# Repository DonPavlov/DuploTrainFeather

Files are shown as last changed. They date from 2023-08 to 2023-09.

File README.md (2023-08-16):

# Duplo Train Controller with ESP32-S3 Feather

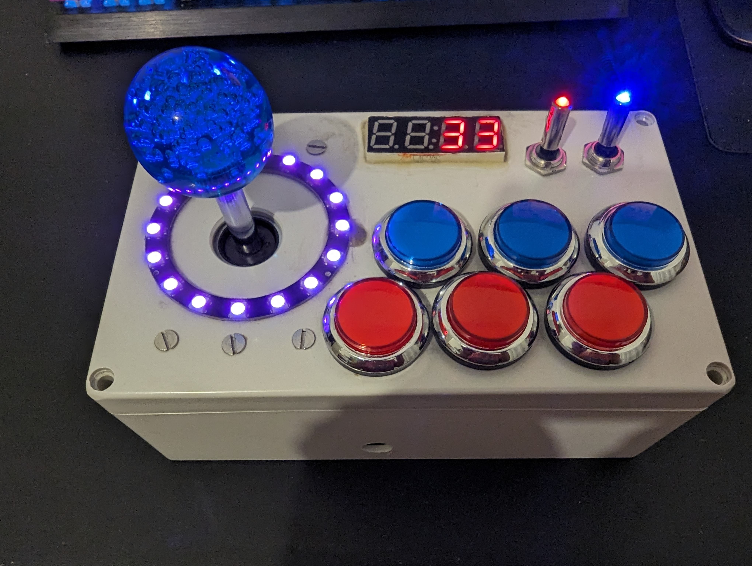
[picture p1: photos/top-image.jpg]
Project Image


This repository contains the code and resources for the 4th iteration of a Duplo train controller built using an ESP32-S3 Feather board. This iteration represents a culmination of learnings from previous iterations and offers enhanced features for controlling a Duplo train wirelessly via Bluetooth. The project features arcade buttons, a joystick, switches, LED indicators, an I2C 4-digit display, a Neopixel 16-pixel ring, and more, all integrated into a customized box.

## Features

- Control Duplo train speed with a joystick
- Trigger lights, sounds, and stop functionality with arcade buttons
- Display train speed on the I2C 4-digit display
- Create dynamic lighting effects using the Neopixel 16-pixel ring
- Use toggle switches for power control and additional functions
- Power everything via USB-C or the included LiPo battery for portability

## Iterations

### 1st Iteration

The first iteration of the project involved utilizing an Arduino Mega to trigger LEDs upon button presses. It served as the foundation for later iterations, focusing on the basic interaction with button inputs and LED outputs.

### 2nd Iteration

In the second iteration, an ESP32 was introduced along with a level shifter, enabling successful control of a Duplo train using button presses. This iteration addressed issues arising from previous AAA battery usage and shorting due to bent power pins.

### 3rd Iteration

The third iteration marked a significant advancement with a completely new PCB design powered by a LiFePO4 battery. However, issues arose concerning power consumption and the ESP32-S3's power requirements, posing challenges in achieving stable operation.

### 4th Iteration (Current)

The current 4th iteration builds upon lessons learned from previous versions. The project utilizes a single ESP32-S3 Feather board to control all functionalities, eliminating the Arduino Mega and AAA battery dependencies. This iteration aims to provide a refined and reliable Duplo train control experience. It is also using a MCP23017 GPIO Expander so only necessary GPIO is used on the Feather and no second microcontroller needs coordination.

## Setup

1. Get a Box to hold everything.
2. Get Arcade Buttons, leds, ESP32-S3 Feather board, MCP23017 Board, LiPo Battery, Neopixel Ring, Joystick, Toggle Switches and Copper-perfboard.
3. Follow the detailed wiring instructions and diagrams provided in the PCB Folder[](pcb/duplo-train-feather.png) 
4. Upload the provided code to your ESP32-S3 Feather board using the Arduino IDE or PlatformIO.

## Wiring Diagram

Please take a closer look inside the pcb folder. 
To open and edit install [Fritzing](https://fritzing.org/)

## Debugging of Feather Boards
Sometimes the ESP32-S3 Feather Board is not able to be flashed.
Follow these steps for a possible solution.
[Possible BugFix/Workaround](https://github.com/espressif/arduino-esp32/issues/8354#issuecomment-1669090415)

# Currently working solution
Upload via OTA, if that fails.
* Press Boot
* Press Reset
* Release Reset
* Release Boot
Flash again at correct COM4.

## License

This project is licensed under the [Unlicense](LICENSE).

---

Designed and developed by DonPavlov.

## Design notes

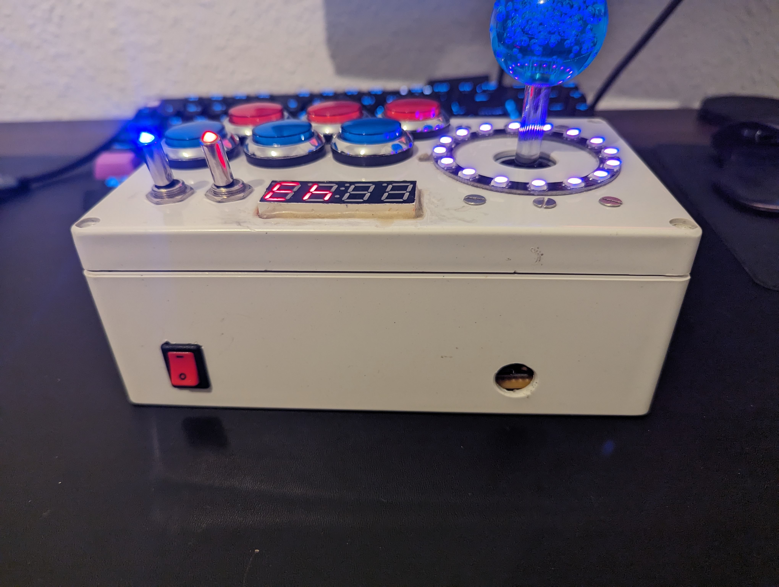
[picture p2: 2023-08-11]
photos/side-image.jpg

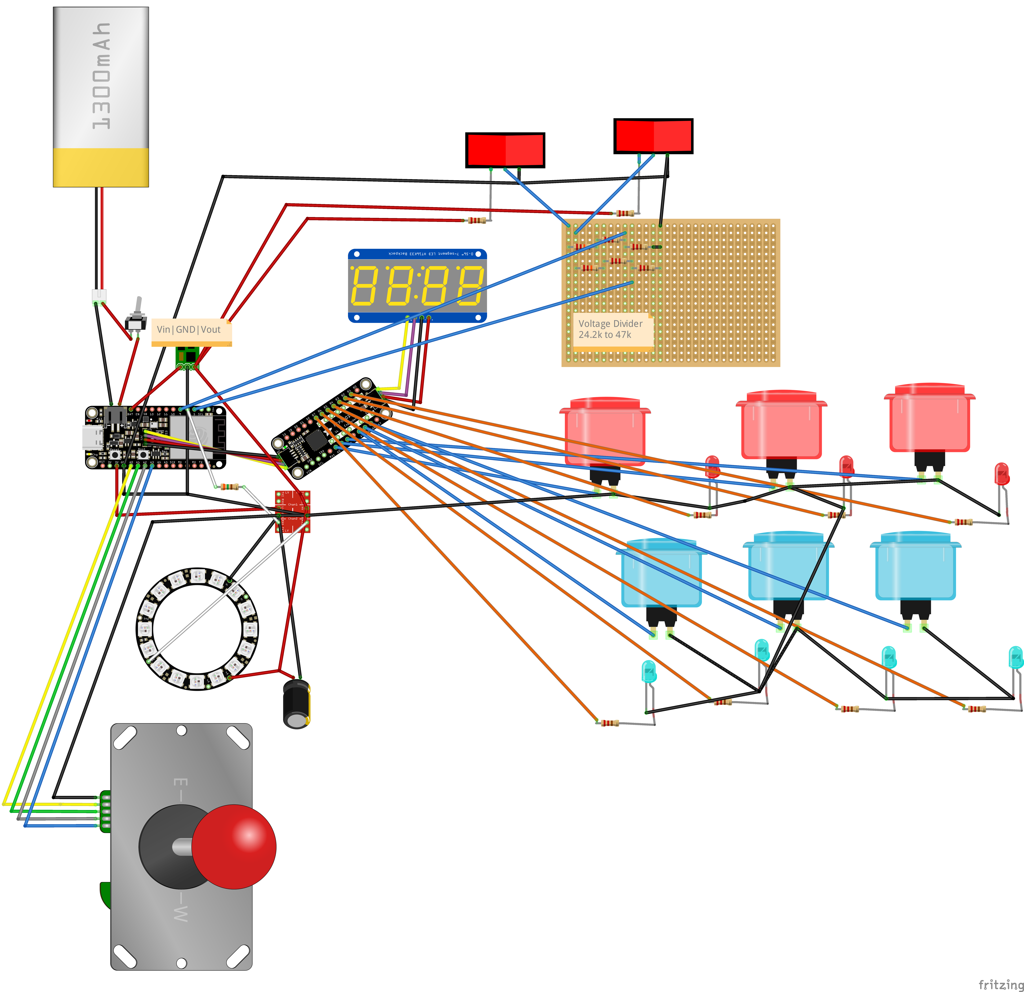
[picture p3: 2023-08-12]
pcb/duplo-train-feather.png

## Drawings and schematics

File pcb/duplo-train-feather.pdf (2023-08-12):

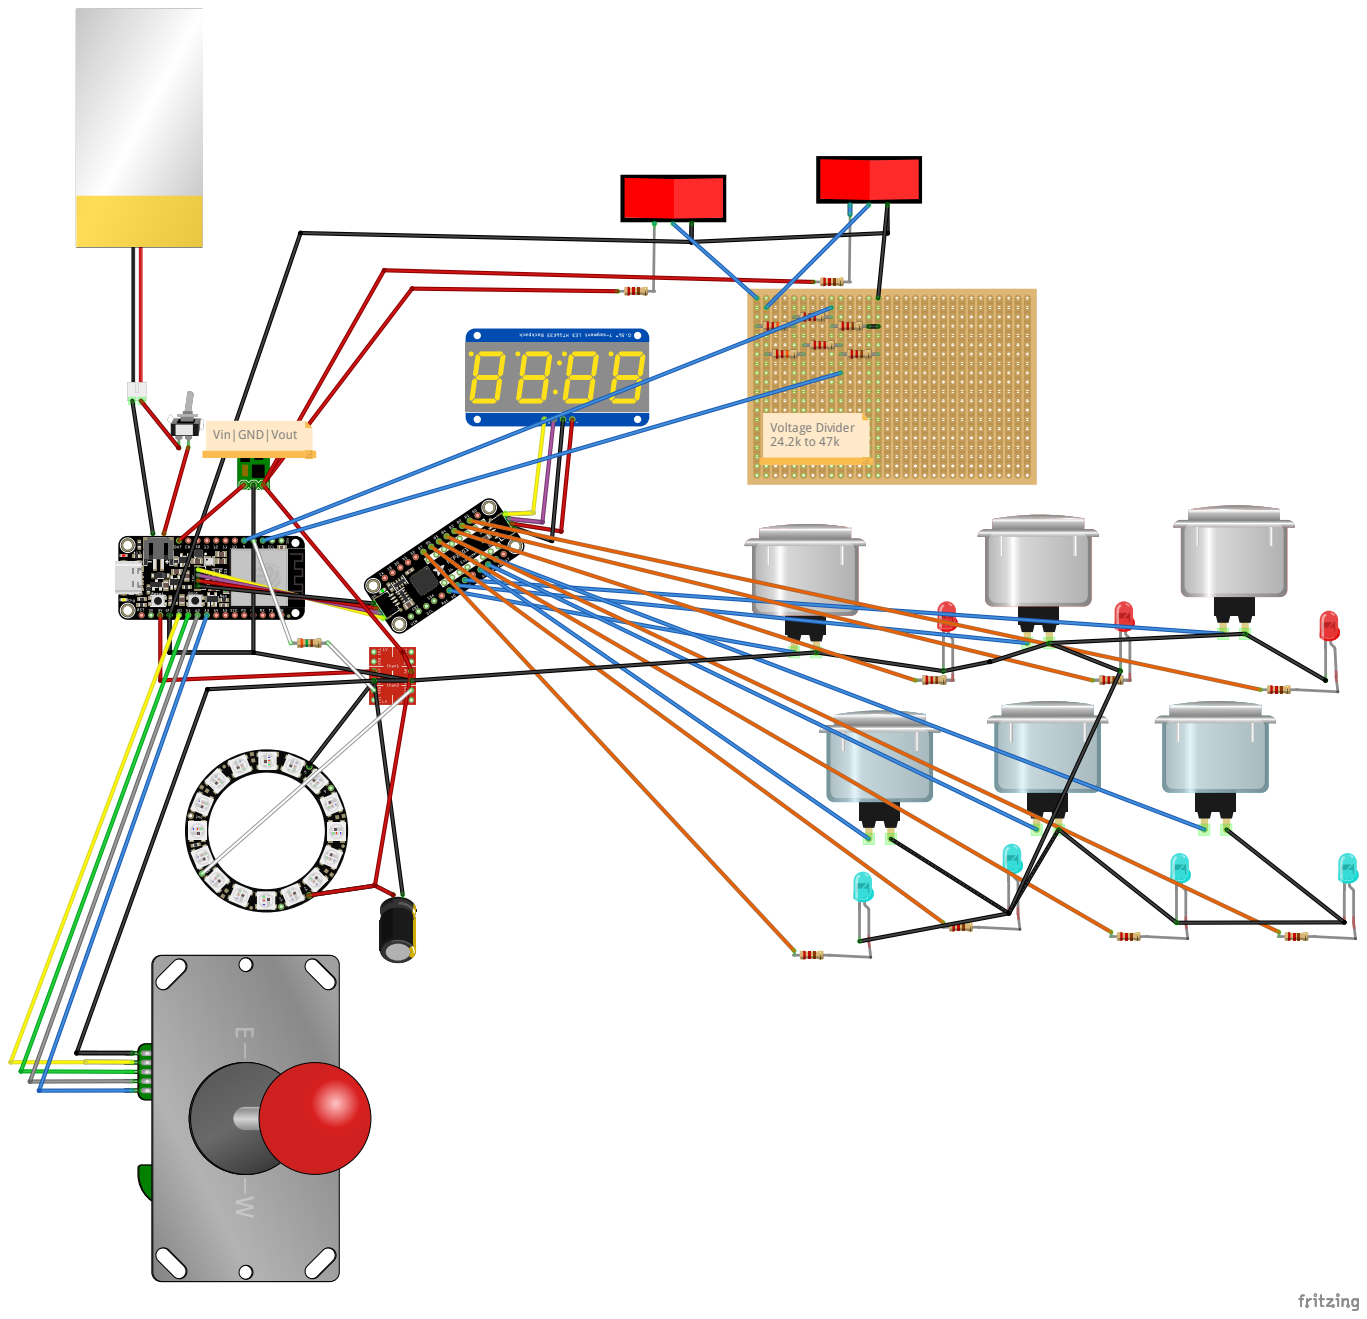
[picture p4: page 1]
Vin|G N; olt a; Divid e

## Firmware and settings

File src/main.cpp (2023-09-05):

#include "main.hpp"
#include <cstring>
#include <string>

#include "io.hpp"
#include "Lpf2Hub.h"
#include "Adafruit_LEDBackpack.h"
#include "Adafruit_NeoPixel.h"
#include <Adafruit_GFX.h>
#include "light_strip.hpp"

#include <Adafruit_MCP23X17.h>
#include "secrets.hpp"
#include <WiFi.h>
#include <ESPmDNS.h>
#include <WiFiUdp.h>
#include <ArduinoOTA.h>

// TODO include #include "Adafruit_MAX1704X.h" // for battery voltage monitoring


// UART1 GPIO 18 RX GPIO17 TX
#define RXD1 (18)
#define TXD1 (17)

Lpf2Hub m_Hub;
volatile int8_t g_speed { 0 };
volatile int8_t g_lastSpeed{ 0 };
bool m_connected{  false };
constexpr size_t buf_size { 32 };

#if (WIFI_MODE == 1)

// Set your Static IP address
IPAddress local_IP(192, 168, 178, 123);

// Set your Gateway IP address
IPAddress gateway(192, 168, 178, 1);

IPAddress subnet(255, 255, 255, 0);
IPAddress primaryDNS(8, 8, 8, 8);   // optional
IPAddress secondaryDNS(8, 8, 4, 4); // optional
#endif // if (WIFI_MODE == 1)
unsigned long startMillis;          // some global variables available anywhere in
                                    // the program
unsigned long currentMillis;
unsigned long wifiMillis;
unsigned long long_periodMillis;
const unsigned long period       { 25 }; // the value is a number of milliseconds
const unsigned long long_period  { 1000 };
const unsigned long wifi_timeout { 10000 };
bool wifiConSkipped              { false };
bool wifiSetupfinished           { false };

bool powerSaveMode { false };
const unsigned long powerSaveThreshold { 600000 }; // 1 minutes in milliseconds
unsigned long lastActivityTime         { 0 };
unsigned long executionTimeMillis { 0 };
unsigned long prevExecutionMillis { 0 };
unsigned long currentExecutionMillis { 0 };
constexpr unsigned long m_hub_delay { 20 };
constexpr unsigned long callback_execution_delay{ 50 };

LightStrip myStrip; // Create an instance of the LightStrip class

Adafruit_7segment matrix = Adafruit_7segment();
IO io_ctrl;

std::map<Commands::Commands, std::string> commandNames = {
  { Commands::Commands::Forward,
    "Forward" },
  { Commands::Commands::Backward,
    "Backward" },
  { Commands::Commands::Stop,
    "Stop" },
  { Commands::Commands::Light,
    "Light"   },
  { Commands::Commands::Refill,
    "Refill"    },
  { Commands::Commands::Horn,
    "Horn"  },
  { Commands::Commands::Steam,
    "Steam" },
  { Commands::Commands::Departure,
    "Departure" },
  { Commands::Commands::Faster,
    "Faster" },
  { Commands::Commands::Slower,
    "Slower" },
  { Commands::Commands::None,
    "None"  }
};

static void colorSensorCb(void      *hub,
                          byte       portNumber,
                          DeviceType deviceType,
                          uint8_t   *pData)
{
  Lpf2Hub *mHub = (Lpf2Hub *)hub;

  if (deviceType == DeviceType::DUPLO_TRAIN_BASE_COLOR_SENSOR)
  {
    int color = mHub->parseColor(pData);

    if (color == (byte)RED)
    {
      mHub->playSound((byte)DuploTrainBaseSound::BRAKE);
    }
    else if (color == (byte)BLUE)
    {
      mHub->playSound((byte)DuploTrainBaseSound::WATER_REFILL);
    }
    else if (color == (byte)YELLOW)
    {
      mHub->playSound((byte)DuploTrainBaseSound::HORN);
    }
  }
}

// TODO add a timeout to the traincommands after having received a successfull command
static void speedometerSensorCb(void      *hub,
                                byte       portNumber,
                                DeviceType deviceType,
                                uint8_t   *pData)
{
  Lpf2Hub *mHub  = (Lpf2Hub *)hub;
  byte     mPort = (byte)DuploTrainHubPort::MOTOR;

  if (deviceType == DeviceType::DUPLO_TRAIN_BASE_SPEEDOMETER)
  {
    int speed = mHub->parseSpeedometer(pData);

    if (speed > 10)
    {
      if (g_speed <= 0)
      {
        g_speed = 50;
      }

      if (g_lastSpeed <= 0)
      {
        Serial1.println("Forward");
        Serial1.print("Speed: ");
        Serial1.println(speed);
        mHub->setBasicMotorSpeed(mPort, g_speed);
        g_lastSpeed = g_speed;
      }
    }
    else if (speed < -10)
    {
      if (g_speed >= 0)
      {
        g_speed = -50;
      }

      if (g_lastSpeed >= 0)
      {
        Serial1.println("Back");
        Serial1.print("Speed: ");
        Serial1.println(speed);
        mHub->setBasicMotorSpeed(mPort, g_speed);
        g_lastSpeed = g_speed;
      }
    }
    else
    {
      Serial1.println("Stop");
      g_speed = 0;
      mHub->stopBasicMotor(mPort);
    }
  }
}

void setup()
{
  pinMode(LED_BUILTIN, OUTPUT);
  Serial1.begin(115200, SERIAL_8N1, RXD1, TXD1);

  io_ctrl.initButtons();

  // Set ESP32 pins 5 and 9 as INPUT_PULLUP
  pinMode(5, INPUT_PULLUP);        // make sure pins don't die, they are connected to the lvl shifter
  pinMode(9, INPUT_PULLUP);        // make sure pins don't die, they are connected to the lvl shifter


  digitalWrite(LED_BUILTIN, HIGH); // turn the LED on (HIGH is the voltage
                                   // level)
  matrix.begin(0x70);              // Init I2C Display


  static uint8_t number = 0;

  matrix.print("1234");
  matrix.writeDisplay();

  myStrip.initialize();

  digitalWrite(LED_BUILTIN, LOW);                          // turn the LED off
  startMillis = wifiMillis = long_periodMillis = millis(); // initial start time

  myStrip.rainbow(true);

  Serial1.println("Setup Train Control");
  m_Hub.init();
  checkConnectionToTrain();

#if (WIFI_MODE == 1)

  // Init wifi for ota updates
  if (!WiFi.config(local_IP, gateway, subnet, primaryDNS, secondaryDNS))
  {
    Serial1.println("STA Failed to configure");
  }
  WiFi.begin(ssid, password);
  #endif // if (WIFI_MODE == 1)
}

void loop()
{
  currentMillis = millis();
  #if (WIFI_MODE == 1)

  // Skip wifi part if not connected
  if (!wifiConSkipped)
  {
    // Connect to wifi If not already connected
    uint8_t status = WiFi.waitForConnectResult();

    if (status != WL_CONNECTED)
    {
      if (currentMillis - wifiMillis >= wifi_timeout)
      {
        wifiConSkipped = true;
        wifiMillis     = currentMillis;
      }
    }

    // If connected to Wifi and wifi setup not yet finished Setup arduino ota
    else if ((status == WL_CONNECTED)
             && (!wifiSetupfinished))
    {
      ArduinoOTA
      .onStart([]() {
        String type;

        if (ArduinoOTA.getCommand() == U_FLASH)
          type = "sketch";
        else // U_SPIFFS
          type = "filesystem";
        lastActivityTime = millis();

        // NOTE: if updating SPIFFS this would be the place to unmount SPIFFS using SPIFFS.end()
        Serial1.println("Start updating " + type);
      })
      .onEnd([]() {
        Serial1.println("\nEnd");
      })
      .onProgress([](unsigned int progress, unsigned int total) {
        Serial1.printf("Progress: %u%%\r", (progress / (total / 100)));
      })
      .onError([](ota_error_t error) {
        Serial1.printf("Error[%u]: ", error);

        if (error == OTA_AUTH_ERROR)
          Serial1.println("Auth Failed");
        else if (error == OTA_BEGIN_ERROR)
          Serial1.println("Begin Failed");
        else if (error == OTA_CONNECT_ERROR)
          Serial1.println("Connect Failed");
        else if (error == OTA_RECEIVE_ERROR)
          Serial1.println("Receive Failed");
        else if (error == OTA_END_ERROR)
          Serial1.println("End Failed");
      });

      ArduinoOTA.begin();

      Serial1.println("Wifi Ready");
      Serial1.print("IP address: ");
      Serial1.println(WiFi.localIP());
      wifiSetupfinished = true;
    }

    if ((wifiSetupfinished) && (!powerSaveMode))
    {
      ArduinoOTA.handle();
    }
  }
  #endif // if (WIFI_MODE == 1)

  if (currentMillis - startMillis >= period) // test whether the period has elapsed
  {
    // TODO fix rainbow effect, make it only continue if function is reentered and continue were it was before.

    io_ctrl.readButtons();
    startMillis = currentMillis;
    myStrip.rainbow(true);
  }

  if (currentMillis - long_periodMillis >= long_period)
  {
    long_periodMillis = millis();

    // TODO only execute if necessary, make sure train can reconnect if connection is lost.
    stateMachine();
  }


  // TODO add timeout if no button press occured for 10 minutes and shutdown most of the functionality, until a button
  // is pressed again or reboot. Or just disable wifi after 5 min to save power but might also be necessary for arduino
  // OTA to have changes....
  // addfunction to stop battery can charge

  if (checkPowerSaveNeeded())
  {
    powerSaving();
  }
}

void powerSaving()
{
  powerSaveMode = true;
#if (WIFI_MODE == 1)
  ArduinoOTA.end(); // Stop OTA server
  Serial1.println("Disable OTA functionality.");
  wifiConSkipped = true;
  WiFi.disconnect();
  WiFi.mode(WIFI_OFF);
  Serial1.println("Disable WiFi");
#endif // if (WIFI_MODE == 1)
  myStrip.rainbow(false);

  for (int i = 0; i < 4; i++)
  {
    matrix.writeDigitRaw(i, 0);
  }
  matrix.writeDisplay();
  Serial1.println("Stop Led Ring and MatrixLeds.");
}

bool checkPowerSaveNeeded()
{
  bool result { false };

  if (!powerSaveMode && (millis() - lastActivityTime >= powerSaveThreshold))
  {
    result = true;
  }
  return result;
}

/*
 #include "Adafruit_MAX1704X.h"

   Adafruit_MAX17048 maxlipo;

   void setup() {
   Serial.begin(115200);
   while (!Serial) delay(10);    // wait until serial monitor opens

   Serial.println(F("\nAdafruit MAX17048 simple demo"));

   if (!maxlipo.begin()) {
    Serial.println(F("Couldnt find Adafruit MAX17048?\nMake sure a battery is plugged in!"));
    while (1) delay(10);
   }
   Serial.print(F("Found MAX17048"));
   Serial.print(F(" with Chip ID: 0x"));
   Serial.println(maxlipo.getChipID(), HEX);
   }

   void loop() {
   Serial.print(F("Batt Voltage: ")); Serial.print(maxlipo.cellVoltage(), 3); Serial.println(" V");
   Serial.print(F("Batt Percent: ")); Serial.print(maxlipo.cellPercent(), 1); Serial.println(" %");
   Serial.println();

   delay(2000);  // dont query too often!
   }
 */
void SendCommand(Commands::Commands cmd)
{
  char cstr[buf_size] = { 0 };
  byte mPort          = (byte)DuploTrainHubPort::MOTOR;

  snprintf(cstr, buf_size, "Command %d: %s", static_cast<int>(cmd), commandNames[cmd].c_str());
  Serial1.println(cstr);

  if (checkConnectionToTrain())
  {
    byte mPort = (byte)DuploTrainHubPort::MOTOR;

    currentExecutionMillis = millis();


    bool execute = currentExecutionMillis >= (prevExecutionMillis + executionTimeMillis);
    snprintf(cstr, buf_size, "Execute: %s", execute ? "true" : "false");
    Serial1.println(cstr);


    switch (cmd)
    {
    case Commands::Commands::Forward:
    {
      if (execute)
      {
        if (0 >= g_speed)
        {
          g_speed = 50;
        }

        m_Hub.setBasicMotorSpeed(mPort, g_speed);
        prevExecutionMillis = currentExecutionMillis;
        executionTimeMillis = 50;
      }
      break;
    }

    case Commands::Commands::Backward:
    {
      if (execute)
      {
        if (0 <= g_speed)
        {
          g_speed = -50;
        }

        m_Hub.setBasicMotorSpeed(mPort, g_speed);
        prevExecutionMillis = currentExecutionMillis;
        executionTimeMillis = 50;
      }

      break;
    }


    case Commands::Commands::Stop:
    {
      if (execute)
      {
        m_Hub.playSound((byte)DuploTrainBaseSound::BRAKE);
        delay(m_hub_delay);
        m_Hub.setBasicMotorSpeed(mPort, 0);
        prevExecutionMillis = currentExecutionMillis;
        executionTimeMillis = 50;
      }

      break;
    }

    case Commands::Commands::Light:
    {
      if (execute)
      {
        Color currentColor = cycleColor();
        Serial1.print("Current Color: ");
        Serial1.println(static_cast<int>(currentColor));
        m_Hub.setLedColor(currentColor);
        prevExecutionMillis = currentExecutionMillis;
        executionTimeMillis = 50;
      }

      break;
    }

    case Commands::Commands::Refill:
    {
      if (execute)
      {
        m_Hub.playSound((byte)DuploTrainBaseSound::WATER_REFILL);
        prevExecutionMillis = currentExecutionMillis;
        executionTimeMillis = 50;
      }

      break;
    }

    case Commands::Commands::Horn:
    {
      if (execute)
      {
        m_Hub.playSound((byte)DuploTrainBaseSound::HORN);
        prevExecutionMillis = currentExecutionMillis;
        executionTimeMillis = 50;
      }

      break;
    }


    case Commands::Commands::Steam:
    {
      if (execute)
      {
        m_Hub.playSound((byte)DuploTrainBaseSound::STEAM);
        prevExecutionMillis = currentExecutionMillis;
        executionTimeMillis = 50;
      }

      break;
    }

    case Commands::Commands::Departure:
    {
      if (execute)
      {
        m_Hub.playSound((byte)DuploTrainBaseSound::STEAM);
        prevExecutionMillis = currentExecutionMillis;
        executionTimeMillis = 50;
      }

      break;
    }

    case Commands::Commands::Faster: {
      if (execute)
      {
        increaseSpeed();

        m_Hub.setBasicMotorSpeed(mPort, g_speed);
        prevExecutionMillis = currentExecutionMillis;
        executionTimeMillis = 50;
      }

      break;
    }

    case Commands::Commands::Slower:
    {
      if (execute)
      {
        decreaseSpeed();

        m_Hub.setBasicMotorSpeed(mPort, g_speed);
        prevExecutionMillis = currentExecutionMillis;
        executionTimeMillis = 50;
      }

      break;
    }

    default:
      executionTimeMillis = 0;
      break;
    }
  }
}

void stateMachine()
{
  if (!checkConnectionToTrain())
  {
    Serial1.println("Train not connected");

    if (m_Hub.isConnecting())
    {
      m_Hub.connectHub();
      Serial1.println("Connecting...");
      delay(100);

      if (m_Hub.isConnected())
      {
        Serial1.println("Connected to Duplo Hub");

        delay(200);
        delay(200);

        // connect speed sensor and activate it for updates
        m_Hub.activatePortDevice((byte)DuploTrainHubPort::SPEEDOMETER,
                                 speedometerSensorCb);
        delay(200);

        // connect color sensor and activate it for updates
        m_Hub.activatePortDevice((byte)DuploTrainHubPort::COLOR,
                                 colorSensorCb);
        delay(200);
        m_Hub.setLedColor(GREEN);
      }
      else
      {
        Serial1.println("Failed to connect to Duplo Hub");
      }
    }
    else
    {
      m_Hub.connectHub();
    }
  }
}

void increaseSpeed()
{
  g_speed += 10;

  if (g_speed > 100)
  {
    g_speed = 100;
  }
  else if (g_speed < -100)
  {
    g_speed = -100;
  }
}

void decreaseSpeed()
{
  g_speed -= 10;

  if ((g_speed < 10) && (g_speed > -10))
  {
    g_speed = 0;
  }
}

int8_t getSpeed()
{
  return g_speed;
}

bool checkConnectionToTrain()
{
  if (m_Hub.isConnected())
  {
    m_connected = true;
  }
  else
  {
    m_connected = false;
  }
  return m_connected;
}

// Function to cycle through colors
Color cycleColor()
{
  static Color currentColor = Color::PINK; // Static variable to store the current color

  int currentIndex = static_cast<int>(currentColor);

  if (currentIndex == static_cast<int>(Color::NONE))
  {
    currentIndex = 0; // Reset to 0 when it's Color::NONE
  }
  else
  {
    currentIndex = (currentIndex + 1) % static_cast<int>(Color::NUM_COLORS);

    if (currentIndex >= static_cast<int>(Color::NUM_COLORS))
    {
      currentIndex = static_cast<int>(Color::NONE); // Reset to None after the modulo operation
    }
  }

  currentColor = static_cast<Color>(currentIndex);

  return currentColor;
}

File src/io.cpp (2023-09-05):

#include "io.hpp"
#include "commands.hpp"
#include "Arduino.h"
#include "Esp.h"
#include <array>
#include <string>


void IO::initButtons()
{
  // Set the inputs for
  pinMode(JOY_N, INPUT_PULLUP);
  pinMode(JOY_S, INPUT_PULLUP);
  pinMode(JOY_W, INPUT_PULLUP);
  pinMode(JOY_E, INPUT_PULLUP);

  // configure IO Expander
  if (!mcp.begin_I2C())
  {
    Serial1.println("Error.");
    int i = 0;

    while (1)
    {
      i++;
      delay(1000);
      Serial1.println("Unable to init MCP23017");

      if (i > 10)
      {
        ESP.restart();
      }
    }
  }
  constexpr size_t buf_size { 32 };
  char cstr[buf_size] = { 0 };

  // Configure Port A pins 0 to 5 as INPUT and enable pull-up resistors on Expandr
  for (int i = 0; i < 6; i++)
  {
    snprintf(cstr, buf_size, "Input Pin %d", i);
    Serial1.println(cstr);
    mcp.pinMode(i, INPUT_PULLUP);
  }

  // Configure Port B pins B5 to B0 as OUTPUT on Expandr
  for (int i = 13; i >= 8; i--)
  {
    snprintf(cstr, buf_size, "Output Pin %d", i);
    Serial1.println(cstr);
    mcp.pinMode(i, OUTPUT);
  }

  // initialize all IO by using the register button function and assign a

  // Setup Pullup and Inputs

  registerButton(btn::BtnNr::BTN0,    Commands::Commands::Stop);
  registerButton(btn::BtnNr::BTN1,    Commands::Commands::Light);
  registerButton(btn::BtnNr::BTN2,    Commands::Commands::Refill);
  registerButton(btn::BtnNr::BTN3,    Commands::Commands::Horn);
  registerButton(btn::BtnNr::BTN4,    Commands::Commands::Steam);
  registerButton(btn::BtnNr::BTN5,    Commands::Commands::Departure);
  registerButton(btn::BtnNr::BTN_J_N, Commands::Commands::Forward);
  registerButton(btn::BtnNr::BTN_J_S, Commands::Commands::Backward);
  registerButton(btn::BtnNr::BTN_J_W, Commands::Commands::Faster);
  registerButton(btn::BtnNr::BTN_J_E, Commands::Commands::Slower);
}

//
void IO::registerButton(btn::BtnNr buttonNr, Commands::Commands command)
{
  btn::ButtonData buttonData;

  buttonData.command       = command;
  buttonData.currentValue  = 1; // Initialize current value
  buttonData.previousValue = 1; // Initialize previous value

  m_buttonsData[buttonNr] = buttonData;
}

// TODO add button lighting to do something, while each button is pressed enable LED.
void IO::readButtons()
{
  uint8_t reg_A = mcp.readGPIOA();

  // split up into array
  constexpr uint8_t arcade_button_nr = 6;
  std::array<uint8_t, arcade_button_nr> arcade_buttons;

  // Update arcade button data
  for (size_t i = 0; i < arcade_button_nr; i++)
  {
    arcade_buttons[i] = (reg_A >> i) & 0x1;

    btn::BtnNr buttonNr         = static_cast<btn::BtnNr>(i);
    btn::ButtonData& buttonData = m_buttonsData[buttonNr];
    buttonData.previousValue = buttonData.currentValue;
    buttonData.currentValue  = arcade_buttons[i];

    // Compare previous and current values and execute the command if needed
    if ((buttonData.currentValue == LOW) && (buttonData.previousValue == HIGH))
    {
      executeCommand(buttonNr);
    }

    // TODO add button lighting to do something
    // While each button is pressed, enable LED
    if (buttonData.currentValue == LOW)
    {
      // Implement your LED lighting logic here
      // For example:
      // turn_on_led(buttonNr);
    }
    else
    {
      // Implement your LED turn-off logic here
      // For example:
      // turn_off_led(buttonNr);
    }
  }


  // Only one joystick is high at a time.
  uint8_t joy_n_input = digitalRead(JOY_N);
  uint8_t joy_s_input = digitalRead(JOY_S);
  uint8_t joy_w_input = digitalRead(JOY_W);
  uint8_t joy_e_input = digitalRead(JOY_E);

  // Joystick button data
  btn::BtnNr joystickButton = btn::BtnNr::MAX_BTN; // Default value for joystick button

  // Update joystick button data
  if (joy_n_input == LOW)
  {
    joystickButton = btn::BtnNr::BTN_J_N;
  }
  else if (joy_s_input == LOW)
  {
    joystickButton = btn::BtnNr::BTN_J_S;
  }
  else if (joy_w_input == LOW)
  {
    joystickButton = btn::BtnNr::BTN_J_W;
  }
  else if (joy_e_input == LOW)
  {
    joystickButton = btn::BtnNr::BTN_J_E;
  }

  // Reset other joystick button values
  for (size_t i = static_cast<int>(btn::BtnNr::BTN_J_N); i < static_cast<int>(btn::BtnNr::MAX_BTN); i++)
  {
    btn::BtnNr buttonNr         = static_cast<btn::BtnNr>(i);
    btn::ButtonData& buttonData = m_buttonsData[buttonNr];
    buttonData.previousValue = buttonData.currentValue;

    if (buttonNr != joystickButton)
    {
      buttonData.currentValue = HIGH;
    }
    else
    {
      buttonData.currentValue = LOW;
    }

    // Compare previous and current values and execute the command if needed
    if ((buttonData.currentValue == LOW) && (buttonData.previousValue == HIGH))
    {
      executeCommand(buttonNr);
    }
  }
}

void IO::executeCommand(btn::BtnNr buttonNr)
{
  btn::ButtonData& buttonData = m_buttonsData[buttonNr];

  lastActivityTime = millis();
  SendCommand(buttonData.command);
}

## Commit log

2023-08-06 Initial Release
    [button_box_new version.fzz]
2023-08-06 fix wifidebuglib not compiling
    [main.cpp]
2023-08-06 fixup everything. somehow manual reset is needed
    [main.cpp]
2023-08-07 add crude i2c numbers and neopixel strips
2023-08-11 add more stuff
    [button_box_new version.fzz, duplo-train-feather.fzz]
2023-08-11 add rainbow power
2023-08-12 update schematic to add voltage divider for the toggle pins
    [duplo-train-feather.fzz]
2023-08-12 update neo pixel ring code
    [duplo-train-feather.fzz]
2023-08-12 update fritzing
    [duplo-train-feather.fzz]
2023-08-13 fix test code now comment out and let it rip
    [main.cpp]
2023-08-14 try out ota code. But not working.
    [main.cpp]
2023-08-14 move button control into its own class
2023-08-15 update everything to use interpret buttons
2023-08-19 add updates for less noise and better control
    [main.cpp]
2023-08-21 try current failing changes
    [main.cpp]
2023-08-22 move stuff around to fix possible issues, disable matrix
    [io.cpp, main.cpp]
2023-08-22 Fix the fucking bug
    [io.cpp, main.cpp]
2023-08-22 add todo and fix forward backward bug
    [main.cpp]
2023-08-22 add more debug prints
2023-09-05 working build. reversing latest changes
    [io.cpp, main.cpp]
2023-09-05 finally enable the Led Color
